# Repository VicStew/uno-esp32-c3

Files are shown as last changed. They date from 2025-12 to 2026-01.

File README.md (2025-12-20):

# ESP32-C6 Dev Board
Personal project involving the creation of an ESP32-C6 Dev Board. 

The ESP32-C6 module comes equipped with:
* A 32-bit processor with a clock speed of upto 160 MHz. 
* Supports Wi-Fi 6 and bluetooth 5 (LE) with onboard antenna and thread, zigbee protocols.
* Comes with built in 320KB ROM, 512KB of HP SRAM, 16KB LP SRAM and 4MB Flash memory.
* Adapts multiple IO interfaces and integrates a full-speed USB PHY interface.

The Dev Board includes support for DC input power.

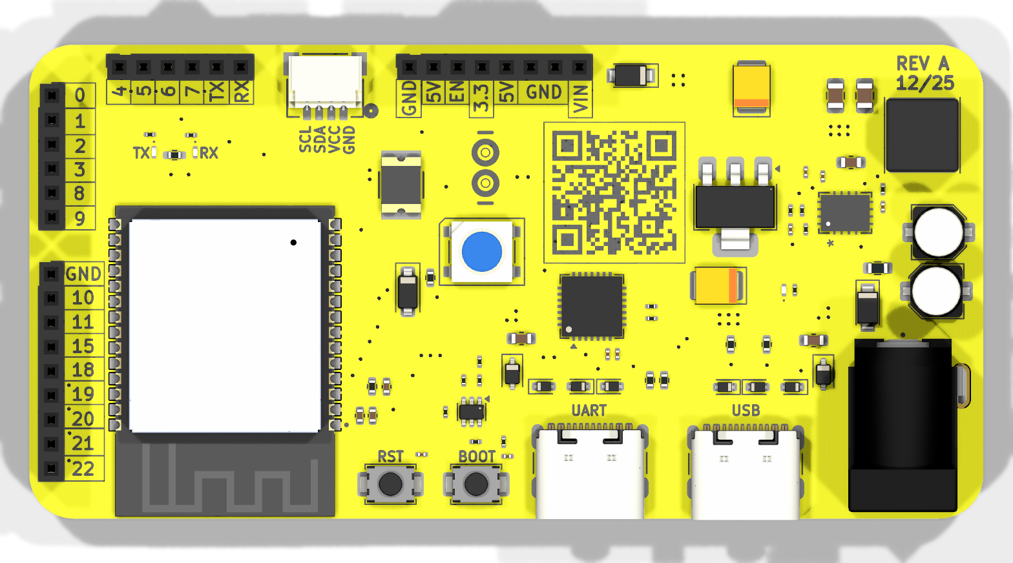
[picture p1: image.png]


## Getting Started

## Development Environment Setup (Ubuntu)

This project supports firmware development for the **ESP32-C6** using both:

* **C/C++ with ESP-IDF** (official Espressif framework)
* **Rust with esp-rs** (modern, type-safe embedded development)

You can use either workflow independently.

---

## Option A: C/C++ Development (ESP-IDF)

ESP-IDF is Espressif’s official SDK and provides full, first-class support for the ESP32-C6.

### 1. Install System Dependencies

Update your system and install required packages:

```bash
sudo apt update
sudo apt install -y \
  git \
  python3 \
  python3-pip \
  python3-venv \
  cmake \
  ninja-build \
  libusb-1.0-0
```

Verify Python:

```bash
python3 --version
```

---

### 2. Install ESP-IDF

Clone ESP-IDF (recommended stable version):

```bash
git clone -b v5.2 --recursive https://github.com/espressif/esp-idf.git
```

Run the installer:

```bash
cd esp-idf
./install.sh esp32c6
```

Activate the ESP-IDF environment:

```bash
source export.sh
```

To make this persistent, you may add the above line to your `~/.bashrc` or `~/.zshrc`.

Verify installation:

```bash
idf.py --version
```

---

### 3. First Hello World (C/C++)

Create a new project:

```bash
idf.py create-project hello_world
cd hello_world
```

Set the target to ESP32-C6:

```bash
idf.py set-target esp32c6
```

(Optional) Configure the project:

```bash
idf.py menuconfig
```

Important settings:

* Serial port selection
* Flash size (if your PCB differs from defaults)

Build, flash, and monitor:

```bash
idf.py build
idf.py flash monitor
```

Expected serial output:

```
Hello world!
```

Your toolchain is alive and talking.

---

## Option B: Rust Development (esp-rs)

Rust development uses the esp-hal ecosystem and the RISC-V toolchain for ESP32-C6.

---

### 1. Install Rust

Install Rust using `rustup`:

```bash
curl --proto '=https' --tlsv1.2 -sSf https://sh.rustup.rs | sh
```

Reload your shell:

```bash
source ~/.cargo/env
```

Install required components:

```bash
rustup component add rust-src
```

---

### 2. Install ESP Rust Toolchain

Install the ESP toolchain manager:

```bash
cargo install espup
```

Install ESP targets and tools:

```bash
espup install
```

Activate the environment:

```bash
source ~/export-esp.sh
```

Add the ESP32-C6 target:

```bash
rustup target add riscv32imac-unknown-none-elf
```

---

### 3. First Hello World (Rust)

Install the project generator:

```bash
cargo install esp-generate
```

Create a new project:

```bash
cargo generate esp-rs/esp-template
```

During setup:

* Select **esp32c6**
* Choose **no_std**
* Enable **UART logging**

Navigate into the project:

```bash
cd your_project_name
```

Build and flash:

```bash
cargo run
```

Expected output over serial:

```
Hello world from Rust!
```

Rust is officially on the board 🦀.

---

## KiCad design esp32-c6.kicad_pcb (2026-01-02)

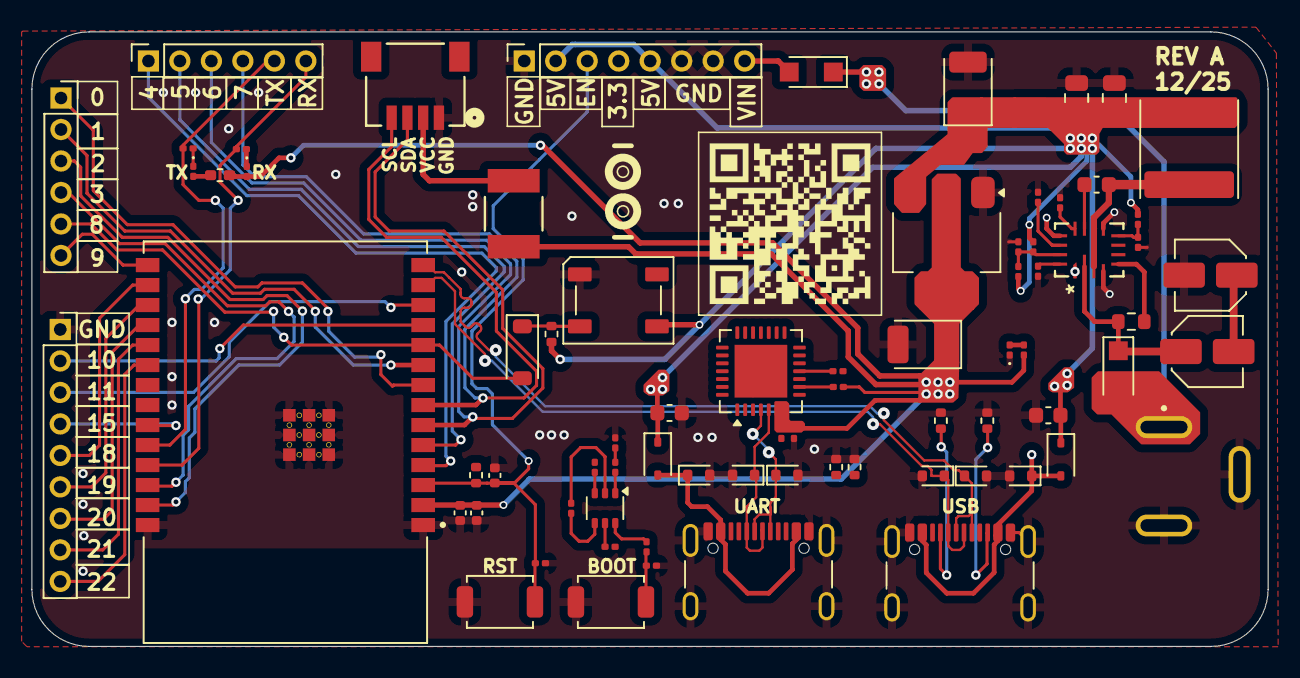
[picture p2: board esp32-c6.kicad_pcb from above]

Board: 2 copper layers, 78.5 x 39.0 mm, 75 parts (0 on the bottom side), 60 nets.

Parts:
C1, C2: 10u/25V; C_0603_1608Metric
C3: 4.7u; C_0201_0603Metric
C4, C5, C6: 0.1u; C_0201_0603Metric
C7: 1u; C_0402_1005Metric
C8: 0.1u; C_0603_1608Metric
C9, C10: 22u, 25V; C_Elec_4x5.4
C11: 10p; C_0201_0603Metric
C12, C13: 22u; C_0805_2012Metric
C14, C17: 1u; C_0201_0603Metric
C15: 4.7n; C_0201_0603Metric
C16, C18: 10u; CP_EIA-3528-12_Kemet-T
C19: 0.1u; C_0402_1005Metric
C20: 10u; C_0402_1005Metric
D1, D2, D3, D4, D5, D13: ESD5Zxx; D_SOD-523
D6, D14: 1N5819WS; D_SOD-323
D7: 1N4148W; D_SOD-123
D8: WS2812B; LED_WS2812B_PLCC4_5.0x5.0mm_P3.2mm
D9, D10: PMEG6020AELR; Nexperia_CFP3_SOD-123W
D11, D12, D15: LED; LED_0201_0603Metric
F1: Polyfuse; FUSE_F050-2
J1, J2: USB_C_Receptacle_USB2.0_14P; USB_C_Receptacle_GCT_USB4105-xx-A_16P_TopMnt_Horizontal
J3: 54-00166; TENSILITY_54-00166
J4: Conn_01x08_Socket; PinSocket_1x08_P2.00mm_Vertical
J5, J8: Conn_01x06_Socket; PinSocket_1x06_P2.00mm_Vertical
J6: Conn_01x04; CONN_SM04B-SRSS-TB_JST
J9: Conn_01x09_Socket; PinSocket_1x09_P2.00mm_Vertical
L1: 10u; L_Changjiang_FNR6045S
Q1: BC847BDW1; SOT-363_SC-70-6
R1, R2, R3, R4: 5.1k; R_0402_1005Metric
R5, R15: 10k; R_0402_1005Metric
R6: 0; R_0402_1005Metric_Pad0.72x0.64mm_HandSolder
R7: 1k; R_0201_0603Metric
R8, R12, R13: 0; R_0201_0603Metric
R9, R10, R11, R14: 10k; R_0201_0603Metric
R16: 68.1k; R_0201_0603Metric
R17: 13k; R_0201_0603Metric
R18: 100k; R_0603_1608Metric
R19: 169k; R_0201_0603Metric
R20: 10; R_0201_0603Metric
R21, R22: 330; R_0201_0603Metric
R23: 5.1k; R_0201_0603Metric
SW1, SW2: SW_Push; SW_SPST_TS-1088-xR020
U1: CP2102N-Axx-xQFN28; QFN-28-1EP_5x5mm_P0.5mm_EP3.35x3.35mm
U2: MPQ9841GLE-5-AEC1-Z; QFN-16_MPQ9841
U3: NCP1117-3.3_SOT223; SOT-223-3_TabPin2
U4: ESP32-C6-WROOM-1-N8; XCVR_ESP32-C6-WROOM-1-N8

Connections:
+3.3V: C3.1, C4.1, C18.1, C19.1, C20.1, D11.2 (A), D12.2 (A), F1.2, J4.4, R6.1, R6.2, R7.1, R15.1, R23.1, U1.6 (VDD), U1.7 (VREGIN), U3.2 (VO), U4.2 (3V3)
+5V: C1.1, C2.1, C11.1, C12.1, C13.1, C16.1, D6.1 (K), D8.1 (VDD), D14.1 (K), J4.2, J4.5, L1.2, R5.1, R16.1, R20.1, U3.3 (VI)
/Barrel Jack/<NO NET>: C8.2, L1.1, U2.3 (SW), U2.10 (SW)
/Barrel Jack/BIAS: C17.1, R20.2, U2.8 (BIAS)
/Barrel Jack/BST: C8.1, U2.11 (BST)
/Barrel Jack/EN: R18.2, U2.5 (EN)
/Barrel Jack/FREQ: R19.1, U2.16 (FREQ)
/Barrel Jack/VOUT: C11.2, R16.2, R17.1, U2.15 (VOUT)
/DA_N: D5.1 (K), J1.A7 (D-), J1.B7 (D-), U1.5 (D-)
/DA_P: D3.1 (K), J1.A6 (D+), J1.B6 (D+), U1.4 (D+)
/DTR: R9.2, R11.2, U1.28 (~DTR)
/GPIO9: C5.2, R8.1, SW1.2
/RTS: Q1.4 (E2), R10.1, U1.24 (~RTS)
/esp32-c6 Pinout/IO0: J5.1, U4.8 (IO0)
/esp32-c6 Pinout/IO1: J5.2, U4.9 (IO1)
/esp32-c6 Pinout/IO2: J5.3, U4.27 (IO2)
/esp32-c6 Pinout/IO3: J5.4, U4.26 (IO3)
/esp32-c6 Pinout/IO4_TMS: J8.1, U4.4 (IO4)
/esp32-c6 Pinout/IO5_TDI: J8.2, U4.5 (IO5)
/esp32-c6 Pinout/IO6_SDA: J6.3, J8.3, U4.6 (IO6)
/esp32-c6 Pinout/IO7_SCL: J6.4, J8.4, U4.7 (IO7)
/esp32-c6 Pinout/IO9_BOOT: J5.6, U4.15 (IO9)
/esp32-c6 Pinout/IO10: J9.2, U4.11 (IO10)
/esp32-c6 Pinout/IO11: J9.3, U4.12 (IO11)
/esp32-c6 Pinout/IO15: J9.4, U4.23 (IO15)
/esp32-c6 Pinout/IO18: J9.5, U4.16 (IO18)
/esp32-c6 Pinout/IO19: J9.6, U4.17 (IO19)
/esp32-c6 Pinout/IO20: J9.7, U4.18 (IO20)
/esp32-c6 Pinout/IO21: J9.8, U4.19 (IO21)
/esp32-c6 Pinout/IO22: J9.9, U4.20 (IO22)
/esp32-c6 Pinout/UART_RX: J8.6, R22.2, U4.25 (TXD0/GPIO16)
/esp32-c6 Pinout/UART_TX: J8.5, R21.2, U4.24 (RXD0/GPIO17)
DB_N: D4.1 (K), J2.A7 (D-), J2.B7 (D-), U4.13 (IO12)
DB_P: D1.1 (K), J2.A6 (D+), J2.B6 (D+), U4.14 (IO13)
EN: C6.2, C7.1, J4.3, R15.2, SW2.2, U4.3 (EN)
GND: C1.2, C2.2, C3.2, C4.2, C5.1, C6.1, C7.2, C10.2, C12.2, C13.2, C14.2, C15.2, C16.2, C17.2, C18.2, C19.2, C20.2, D1.2 (A), D2.2 (A), D3.2 (A), D4.2 (A), D5.2 (A), D8.3 (VSS), D13.2 (A), D15.1 (K), J1.A1 (GND), J1.A12 (GND), J1.B1 (GND), J1.B12 (GND), J1.S1 (SHIELD), J2.A1 (GND), J2.A12 (GND), J2.B1 (GND), J2.B12 (GND), J2.S1 (SHIELD), J3.B, J3.C, J4.1, J4.6, J4.7, J6.1, J9.1, R1.2, R2.2, R3.2, R4.2, R11.1, R12.2, R14.2, R17.2, R19.2, SW1.1, SW2.1, U1.3 (GND), U1.29 (GND), U2.1 (PHASE), U2.4 (PGND), U2.9 (PGND), U2.13 (AGND), U3.1 (GND), U4.1 (GND), U4.28 (GND), U4.29_1 (GND), U4.29_2 (GND), U4.29_3 (GND), U4.29_4 (GND), U4.29_5 (GND), U4.29_6 (GND), U4.29_7 (GND), U4.29_8 (GND), U4.29_9 (GND)
IO8: D7.1 (K), J5.5, U4.10 (IO8)
unnamed: C9.2, C10.1
unnamed: D7.2 (A), D8.4 (DIN), R5.2
unnamed: D10.2 (A), J4.8
unnamed: D11.1 (K), R21.1
unnamed: D12.1 (K), R22.1
unnamed: D15.2 (A), R23.2
unnamed: J1.A5 (CC1), R3.1
unnamed: J1.B5 (CC2), R1.1
unnamed: J2.A5 (CC1), R4.1
unnamed: J2.B5 (CC2), R2.1
unnamed: F1.1, J6.2
unnamed: Q1.2 (B1), R10.2
unnamed: Q1.6 (C1), R8.2
unnamed: Q1.1 (E1), R9.1
unnamed: Q1.5 (B2), R12.1
unnamed: Q1.3 (C2), R13.2
unnamed: R7.2, U1.9 (~RST)
unnamed: R14.1, U1.11 (~SUSPEND)
unnamed: C15.1, U2.14 (SS)
unnamed: C14.1, U2.12 (VCC)
VBUS_A: D2.1 (K), D6.2 (A), J1.A4 (VBUS), J1.A9 (VBUS), J1.B4 (VBUS), J1.B9 (VBUS), U1.8 (VBUS)
VBUS_B: D13.1 (K), D14.2 (A), J2.A4 (VBUS), J2.A9 (VBUS), J2.B4 (VBUS), J2.B9 (VBUS)
VIN: C9.1, D9.1 (K), D9.2 (A), D10.1 (K), J3.A, R18.1, U2.2 (VIN)

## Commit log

2025-11-15 initial commit: usb to uart
    [esp32-c6.kicad_pcb, esp32-c6.kicad_sch]
2025-11-20 usb-to-uart bridge change
    [esp32-c6.kicad_sch]
2025-11-23 wroom change + boot & reset
    [esp32-c6.kicad_sch]
2025-11-24 barrel jack mpq9841 +
    [barrel_jack.kicad_sch, esp32-c6.kicad_sch]
2025-11-25 NCP1117-3.3 change
    [barrel_jack.kicad_sch, esp32-c6.kicad_sch]
2025-11-29 header pins + footprint assignment
    [barrel_jack.kicad_sch, c6_pinout.kicad_sch, esp32-c6.kicad_sch]
2025-12-08 pcb component layout
    [barrel_jack.kicad_sch, c6_pinout.kicad_sch, esp32-c6.kicad_pcb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]
2025-12-12 layout + power pin traces
    [barrel_jack.kicad_sch, c6_pinout.kicad_sch, esp32-c6.kicad_pcb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]
2025-12-19 final tracing + pcb layers + colors
    [barrel_jack.kicad_sch, c6_pinout.kicad_sch, esp32-c6.kicad_pcb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]
2025-12-20 minor silkscreen changes + readme file
    [esp32-c6.kicad_pcb]
2025-12-20 MPQ9841GLE-5-AEC1-Z model + image update
    [esp32-c6.kicad_pcb]
2026-01-02 Refinement to pcb and schematic layout
    [barrel_jack.kicad_sch, c6_pinout.kicad_sch, esp32-c6.kicad_pcb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]
